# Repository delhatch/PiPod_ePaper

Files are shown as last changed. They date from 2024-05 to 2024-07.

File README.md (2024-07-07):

# PiPod_ePaper
This project takes the github.com/delhatch/PiPod project (which was derived from github.com/BramRausch/PiPod) and replaces the LCD screen with an e-Paper screen.
<table border="1">
  <tr>
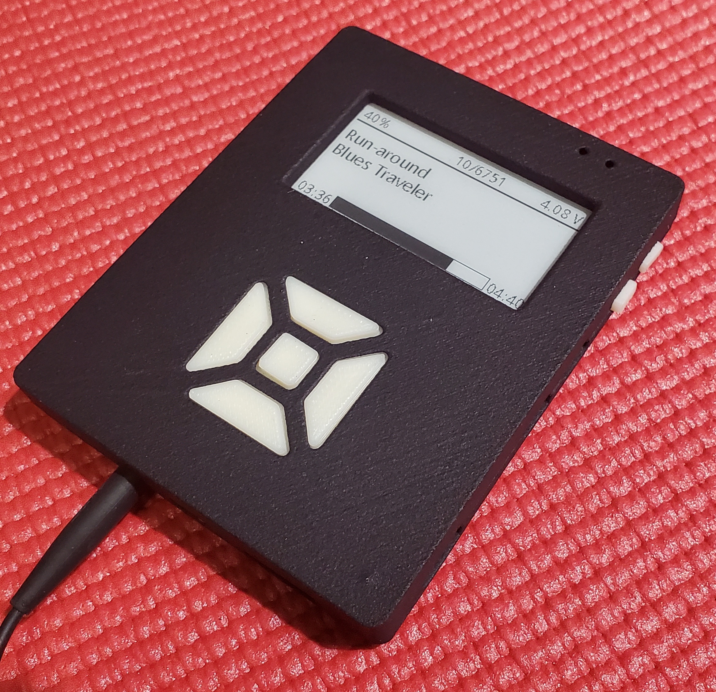
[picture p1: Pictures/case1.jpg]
   <td></td>
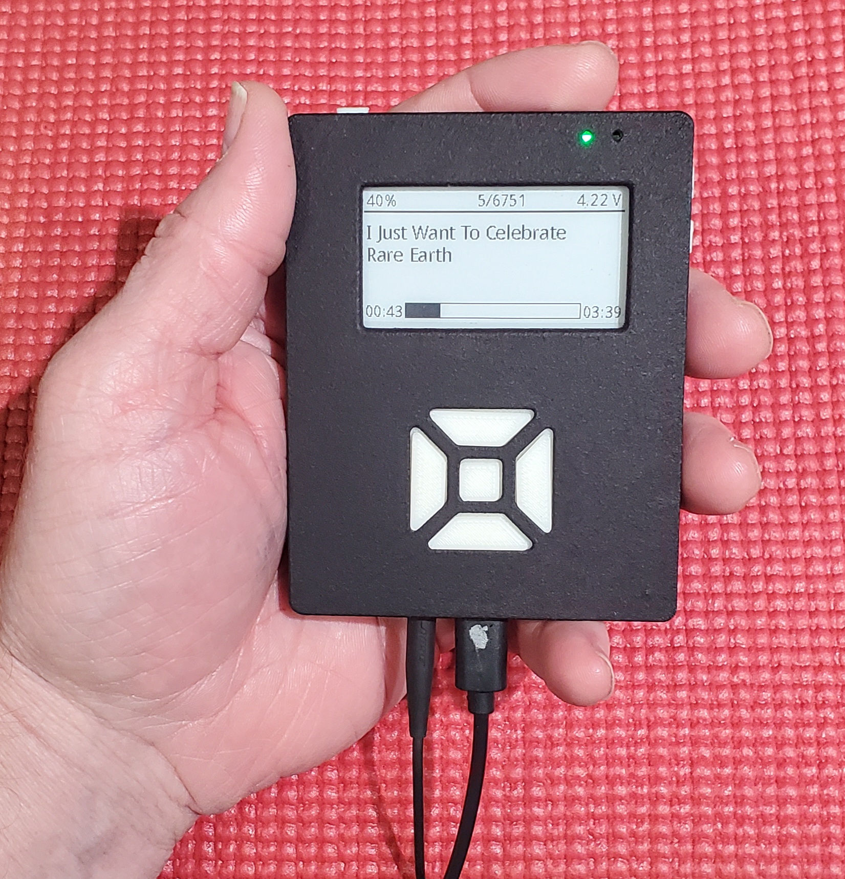
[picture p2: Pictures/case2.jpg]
   <td></td>
  </tr>
  <tr>
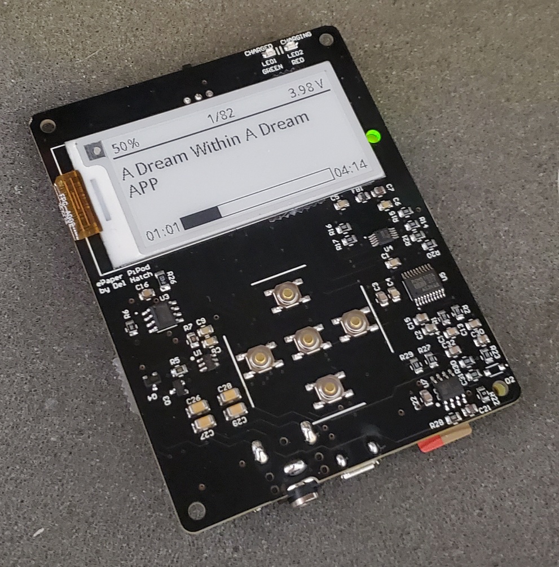
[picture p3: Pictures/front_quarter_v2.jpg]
   <td></td>
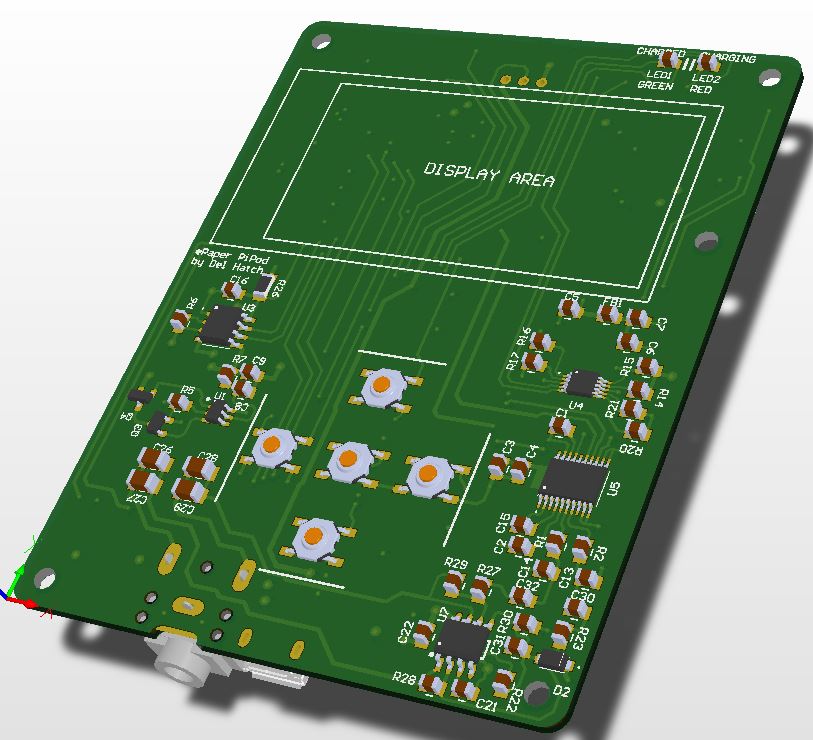
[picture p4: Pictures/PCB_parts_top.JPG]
   <td></td>
  </tr>
  <tr>
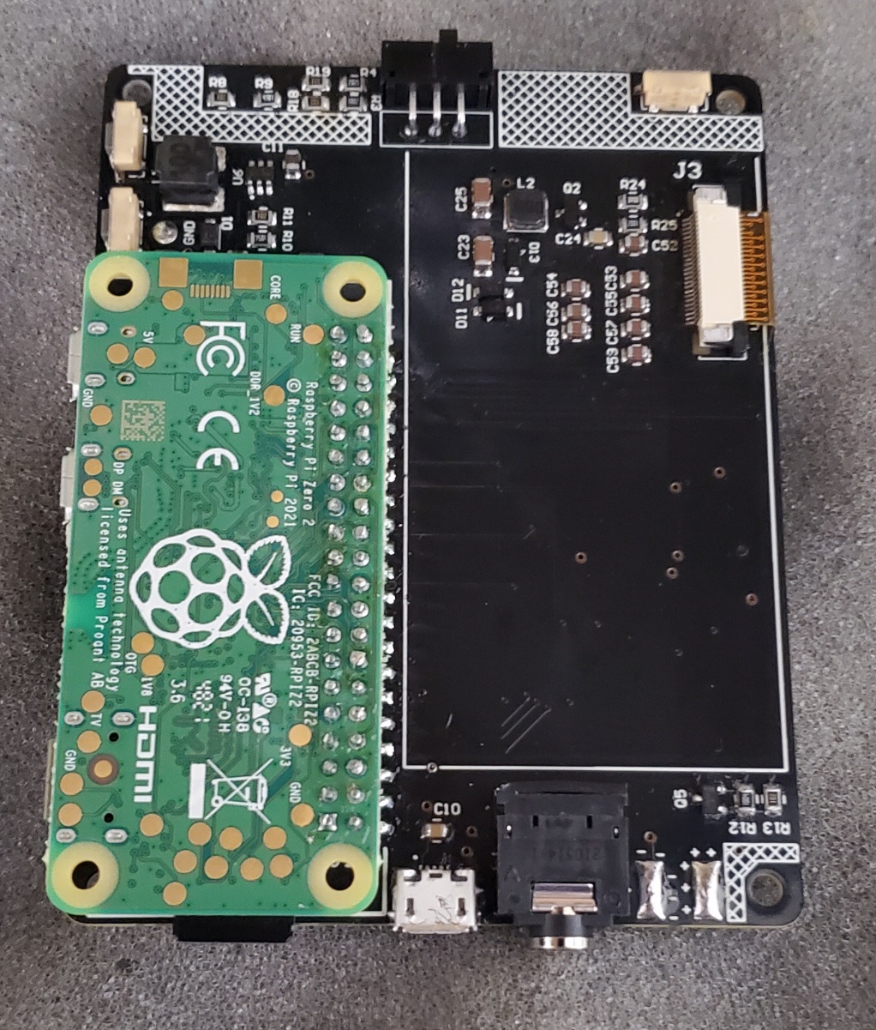
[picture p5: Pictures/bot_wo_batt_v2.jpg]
   <td></td>
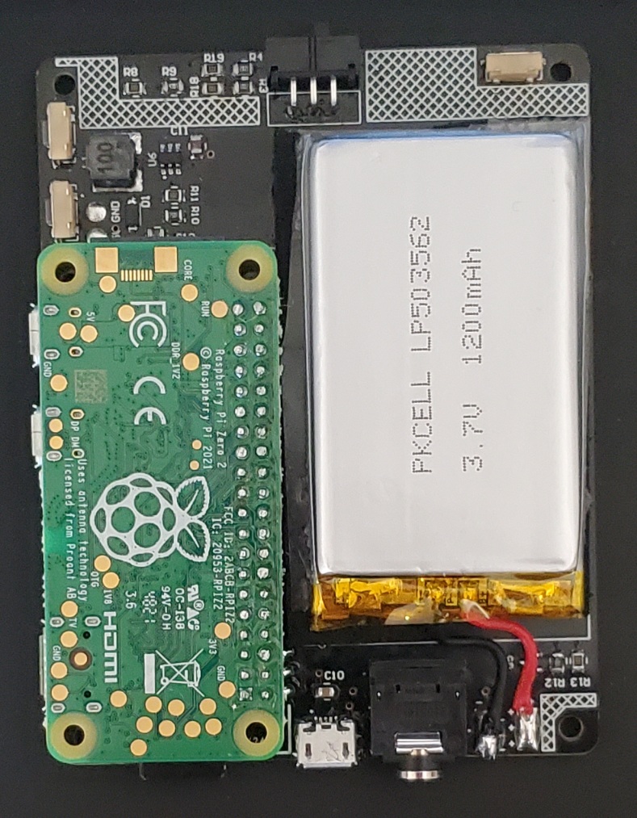
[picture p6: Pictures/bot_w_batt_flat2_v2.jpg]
   <td></td>
  </tr>
  <tr>
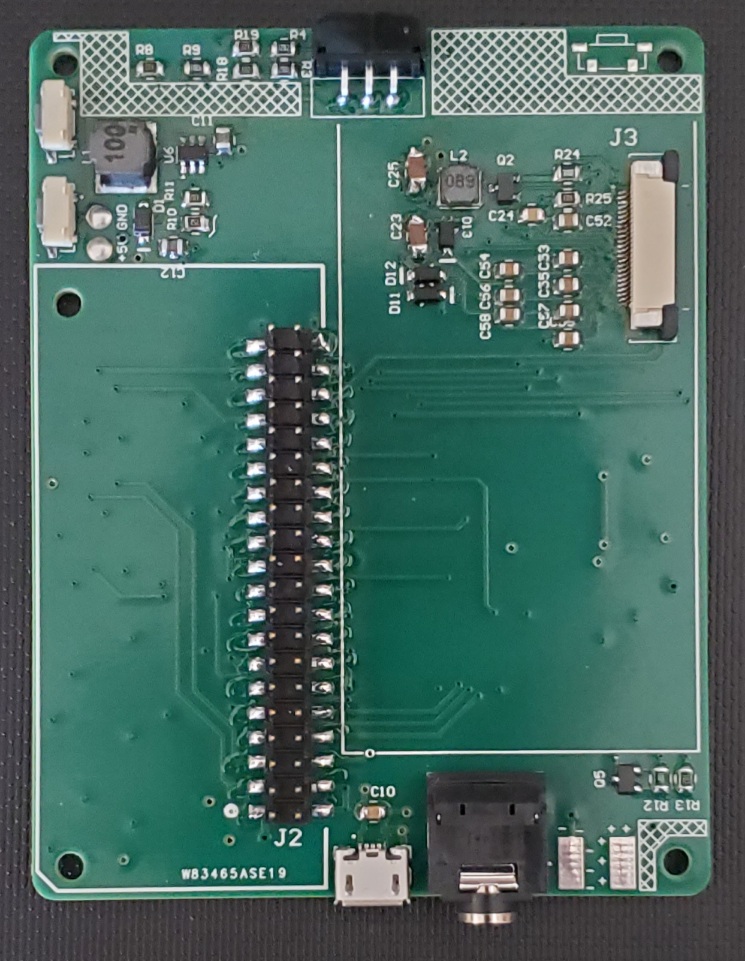
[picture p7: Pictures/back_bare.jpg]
   <td></td>
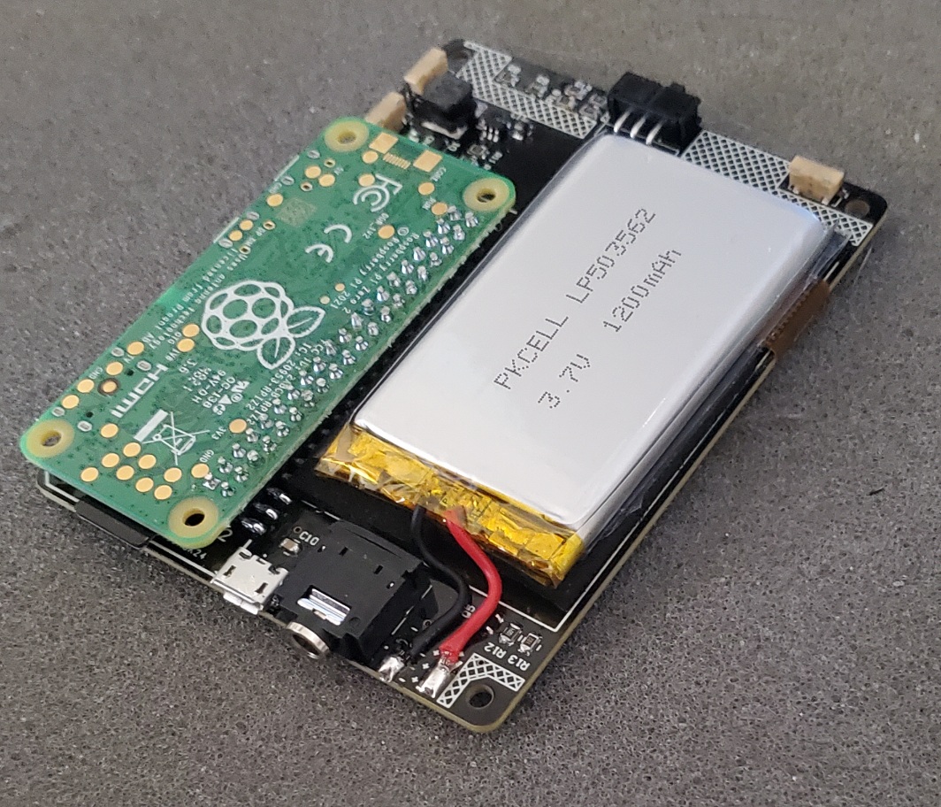
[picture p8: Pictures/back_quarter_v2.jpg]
   <td></td>
  </tr>
</table>
<h3>Motivation</h3>
<p>The goal of this project was switching from a 2.2" 320x240 LCD screen to a 2.13" 250x122 e-Paper screen (from Waveshare) in order to extend the battery run-time.</p>
<p>Using the project's standard 1200 mAh battery, the continuous play time is now <b>4 hours, 48 minutes</b>. Since a USB power supply is rarely far away, this seems sufficient.</p>
<p>In addition to using an e-paper screen, I also added a headphone amplifier based on the TP6113 IC. Note: This amplifier is rated at 40 mW, which does not sound like a lot of power, but even with inefficient headphones this equates to 108 dBSPL (equivalent to a gas lawn mower at 1m), which is far too loud for sustained listening. Watch your volume setting!</p>
<h3>Project Derivation</h3>
<p>This project is derived from github.com/delhatch/PiPod_Zero2W. This repository has changes to impliment the use of the e-Paper screen, along with other minor bug fixes.</p>
<h3>Structural Changes</h3>
<p>I have changed the OS to the "lite" version: 2024-03-15-raspios-bookworm-arm64-lite.img.xz This change reduces power consumption by ~20 mA, which is a 9% savings, so reasonably significant.</p>
<p>Also moved from Pygame to Pillow for the screen graphics.</p>
<p>Then I got rid of Pygame completely, since I was only using it for the key stroke buffer, and the Python keypad library was already taking care of that. Eliminating Pygame reduced power consumption by 9.2% when idle, and by 5.2% when playing music.</p>
<h3>Status</h3>
<p>28 June 2024: I built a unit with the Rev2 PCB (black PCB, see pics). It works great. The Rev3 (current) case files appear to be acceptable.</p>
<h3>Power Savings</h3>
<p>With the LCD screen, with the backlight on, during playback, the current draw is <b>266 mA</b>.</p>
<p>With the LCD screen, with the backlight off, during playback, the current draw is <b>220 mA</b>.</p>
<p>With the e-Paper screen, during playback, the current draw is <b>175 mA</b>.</p>
<p>Having eliminated Pygame, the current draw is down to only <b>166 mA</b>.</p>
<p>So the e-Paper screen is definitely a major improvement in battery life (playback time), and also useability because there is no anxiety about leaving an LCD backlight on.</p>
<h3>Known Bugs</h3>
<ul>
<li>None.</li>
</ul>
<h3>Features TODO</h3>
<ul>
  <li>Test "current draw vs. various refresh rates" for the top (Playing) screen. It updates every 5 seconds, which isn't bad actually, but if this can be reduced without costing too much power, it might be worth it. TBD.</li> 
  <li>Eliminate flashing screen on sub-menus.</li>
  <li>Impliment an "Adjust Audio EQ" screen.</li>
  <li>Restore playback state on power-up (restore the play list, and the currently-playing song).</li>
  <li>Add the use of a GPIO to mute the headphone amp on power-up?</li>
  <li>Determine if there is a need to install all of the waveshare github. Just need the 2 files in this repo?</li>
</ul>
<h3>Instructions</h3>
<p>Completion of these instructions takes about 40 minutes, not including the time transferring the music files.</p>
<p>The bare PC board and case parts can be ordered via this link at <a href="https://www.pcbway.com/project/shareproject/ePaper_PiPod_MP3_music_player_a6adf3e1.html">PCBWay</a>. For the case parts (top, bottom and frame parts) I specified 3D printing in Nylon: PA-12 with 35% glass fill. For the navigation and side buttons, 3D printing in any cheap white plastic will do.</p>
<a href="https://www.pcbway.com/project/shareproject/ePaper_PiPod_MP3_music_player_a6adf3e1.html">PCB from PCBWay</a>
<p>Instructions:</p>
<ul>
  <li>Download the OS file "2024-03-15-raspios-bookworm-arm64-lite.img.xz" or newer.</li>
  <li>Using rufus-3.22.exe (or similar), burn the image to a 128GB micro-SD card.</li>
  <li>Assuming you have a fully-assembled PiPod hardware: Connect an HDMI monitor to the Pi Zero 2 W. Also connect a USB expander hub such as the SmartQ H302S to the Pi Zero usb connector. Connect a USB keyboard to the hub.</li>
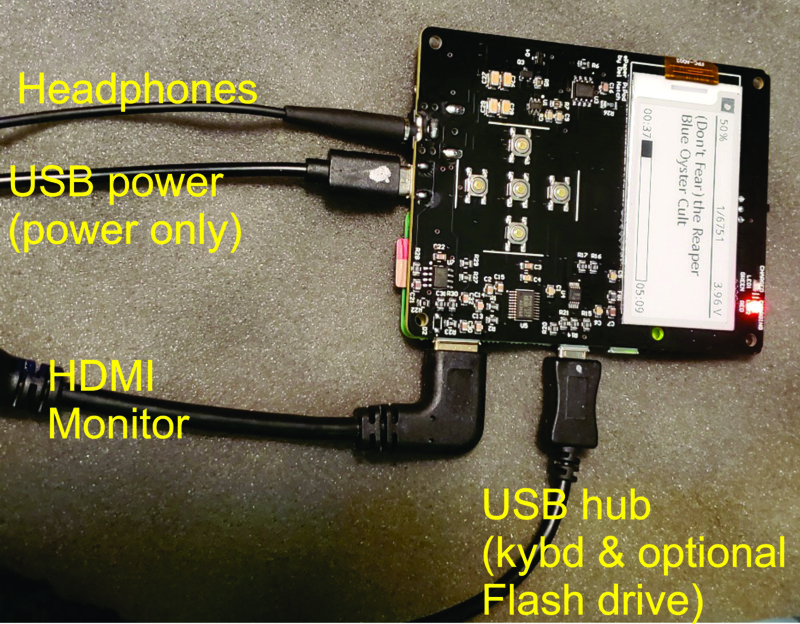
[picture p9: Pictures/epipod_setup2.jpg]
  
  <li>Insert the SD card into the Pi Zero 2 W slot.</li>
  <li>Apply power (from a plug-in USB power supply) to the USB connector at the bottom of the PiPod.</li>
  <li>Power-up and go through the configuration screens. Create the user "pi" with a password of your choosing. Reboot and log in.</li>
  <li>At the prompt: <code>sudo raspi-config</code>
    <ul>
      <li>Go into Menu Item #1, then select S1. Enter the SSID and passphrase for your wi-fi.</li>
      <li>Select menu item #1, then select S5 (Boot/Auto-login) select and enable "Console Autologin".</li>
      <li>From the top menu, select #3 "Interface Options" then select and enable I1 "Enable SSH".</li>
      <li>From the top menu, select #3 "Interface Options" then select and enable I4 "Enable I2C".</li>
      <li>Select "Back" to top screen, then "Finish" and then reboot.</li>
    </ul></li>
  <li>Type: <code>sudo nano /boot/firmware/config.txt</code> and make the following changes:
    <ul>
      <li>If necessary, un-comment <tt>dtparam=spi=on</tt> (to turn on the SPI port)</li>
      <li>comment-out the <tt>dtparam=audio=on</tt> line</li>
      <li>If necessary, un-comment the line <tt>dtparam=12c_arm=on</tt></li>
      <li>At the end of the file, add a line: <tt>dtoverlay=hifiberry-dac</tt></li>
      <li><tt>CTRL-O</tt> and <tt>ENTER</tt> and <tt>CTRL-X</tt> to save and exit.</li>
  </ul>
</li>
  <li><code>sudo reboot</code></li>
  <li>Enter the following lines to install the required packages:
  <ul>
    <li><code>sudo apt install python3</code></li>
    <li><code>sudo apt install build-essential python3-dev python3-smbus -y</code></li>
    <li><code>sudo apt install git -y</code></li>
    <li><code>sudo apt install python3-vlc -y</code></li>
    <li><code>sudo apt install python3-alsaaudio -y</code></li>
    <li><code>sudo apt install pulseaudio -y</code></li>
    <li><code>sudo apt install python3-taglib -y</code></li>
    <li><code>sudo apt install python3-spidev -y</code></li>
    <li><code>sudo apt install python3-gpiozero -y</code></li>
    <li><code>sudo apt install python3-pip -y</code></li>
    <li><code>sudo apt install python3-pil -y</code></li>
    <li><code>sudo apt install python3-numpy -y</code></li>
  </ul>
</li>
<li><code>sudo reboot</code></li>
<li>Verify that the audio is working. Plug headphones into the PiPod and type:
  <ul>
    <li><code>sudo raspi-config</code></li>
    <li>Select line #1, then #2 "Audio"
    <li>Select snd_rpi_hifiberry_dac then Finish</li>
    <li>type: <code>amixer set Master 50%</code></li>
    <li>type: <code>speaker-test -c2</code></li>
    <li>Verify that audio is coming from the headphones and not the HDMI monitor.</li>
    <li><tt>CTRL-C</tt> to finish and quit.</li>
  </ul>
</li>
<li>Install the Adafruit_GPIO library:
  <ul>
    <li>from the home directory (<code>~/</code>) type: <code>git clone https://github&#46;com/adafruit/Adafruit_Python_GPIO.git</code></li>
    <li><code>cd Adafruit_Python_GPIO</code></li>
    <li><code>sudo python3 setup.py install</code></li>
  </ul>
<li>Install the Adafruit Blinka library:
  <ul>
    <li><code>cd ~/</code></li>
    <li><code>sudo pip3 install --break-system-packages Adafruit-Blinka</code></li>
  </ul>
</li>
<li>Install the waveshare e-Paper libraries:
  <ul>
    <li><code>cd ~/</code></li>
    <li><code>git clone https://github&#46;com/waveshare/e-Paper.git</code></li>
    <li><code>sudo pip3 install --break-system-packages waveshare-epaper epd-library</code></li>
  </ul></li>
<li><code>sudo reboot</code></li>
<li>Now fetch the e-Paper MP3 player software from this repository:
  <ul>
    <li><code>cd ~/</code> then type: <code>git clone https://github&#46;com/delhatch/PiPod_ePaper.git</code></li>
    <li><code>cd PiPod_ePaper</code></li>
    <li><code>mv launch.sh ~/.</code></li>
    <li><code>cd ~/</code></li>
    <li><code>chmod 777 launch.sh</code></li>
    <li><code>mkdir .config/systemd</code></li>
    <li><code>mkdir .config/systemd/user</code></li>
    <li><code>cd PiPod_ePaper</code></li>
    <li><code>mv pipod.service ~/.config/systemd/user/.</code></li>
    <li><code>mv -f epd2in13_V4.py ~/e-Paper/RaspberryPi_JetsonNano/python/lib/waveshare_epd/.</code></li>
    <li><code>mv -f epdconfig.py ~/e-Paper/RaspberryPi_JetsonNano/python/lib/waveshare_epd/.</code></li>
  </ul>
</li>
<li>Create the directory: <code>mkdir ~/Music</code></li>
<li>Move your music files into this Music directory. You can do this two ways:
  <ul>
    <li>Method 1: Insert a USB Flash stick into the USB hub, and cp the files over.
      <ul>
        <li><code>sudo mount /dev/sda1 /mnt/usb</code> (You'll need to sudo mkdir the /mnt/usb directory)</li>
        <li>After copying, <code>sudo umount /mnt/usb</code> then remove the USB stick.</li>
      </ul>
    </li>
    <li>Method 2: Type: <code>ifconfig</code> and note the IP address. Use the application WinSCP, and use the SFTP protocol, to copy media files from a Windows computer to the PiPod.</li>
  </ul>
</li>
<li>You should now be able to launch the PiPod software, with everything working.
  <ul>
    <li>cd into the directory: <code>cd ~/PiPod_ePaper/Software</code></li>
    <li>Type: <code>python3 main.py</code></li>
    <li>Note that when launching for the first time, it will scan the music files and create an index file. This may take a minute or two.</li>
  </ul>
</li>
<li>To have the PiPod automatically run the player automatically on power-on:
  <ul>
    <li>To activate the pipod.service file, at the prompt, type: <code>systemctl --user enable pipod.service</code></li>
    <li>Reboot. If there are problems, type: <code>systemctl --user status pipod.service</code> to see if the service launched.</li>
  </ul>
</li>
  <li>To minimize battery power consumption: disable wifi, bluetooth, and reduce the CPU clock speed.
  <ul>
    <li><code>sudo nano /boot/firmware/config.txt</code></li>
    <li>After the line "dtparam=spi=on add these new lines:
    <ul>
      <li><code>dtoverlay=disable-wifi</code></li>
      <li><code>dtoverlay=disable-bt</code></li>
    </ul></li>
    <li>Under the line "Enable DRM VC4 V3D driver", comment out the 2 lines that follow.</li>
    <li>Comment out the line <code>display_auto_detect=1</code></li>
    <li>Under the line "Run as fast as firmware board allows"
      <ul>
        <li>comment out <code>arm_boost=1</code></li>
        <li>add the lines:
          <ul>
            <li><code>arm_freq=150</code></li>
            <li><code>core_freq=150</code></li>
            <li><code>over_voltage=-4</code></li>
          </ul></li></li>
      </ul>
  </li>
</ul>
<h3>Operating Procedure</h3>
<p>To charge the battery, slide the top power switch to the left. Connect a USB power supply to the USB jack at the bottom of the PiPod. Applying power will start charging the battery, and will also boot the PiPod.</p>
<p>To shutdown the PiPod, press the up arrow to get into the menu tree. Press the down arrow to "Shutdown". Press the middle button.</p>
<p>To operate from battery power, you MUST start with the ePiPod in the shutdown state. Do not run from USB power (power switch to the left) and then slide the power switch to the right (battery power). This causes a power glitch. Simply start with an ePiPod in the shutdown state, and slide the power switch to the right. Wait for it to boot.</p>
<p>While operating from battery power, you can plug (and unplug) the bottom USB jack into a power source to charge the battery.</p>
<p>To shutdown from battery power, find and press the "Shutdown" command as above. After 5 seconds (and with the bottom USB jack <b>NOT</b> connected to a power source), slide the top power switch to the left.</p>

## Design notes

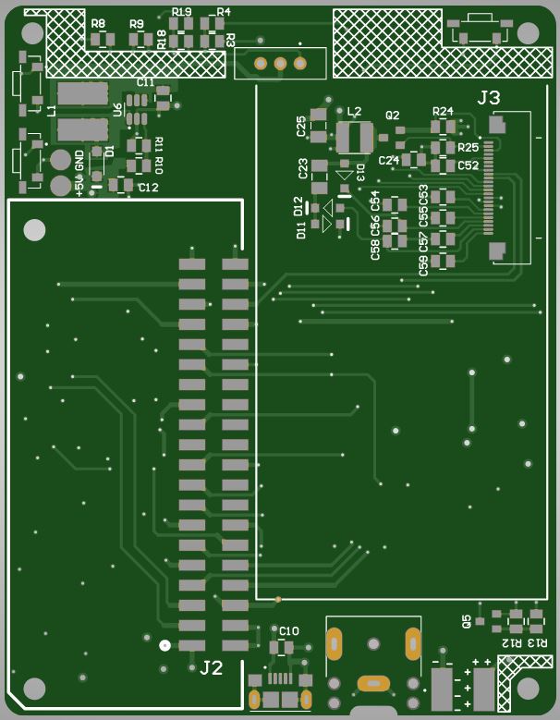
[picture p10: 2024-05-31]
Pictures/PCB_bottom.JPG

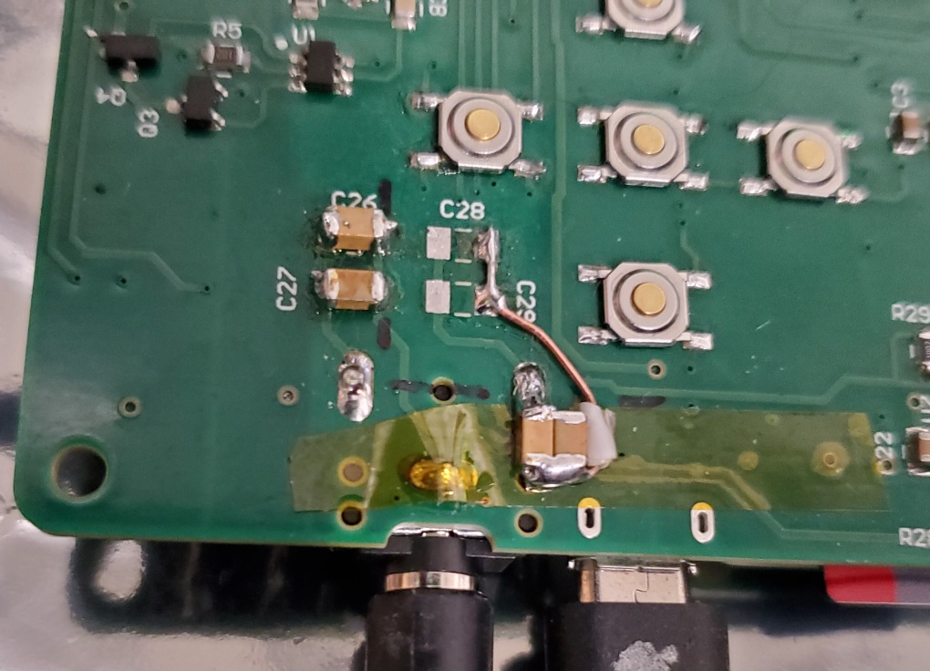
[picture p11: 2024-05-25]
Pictures/patch.jpg

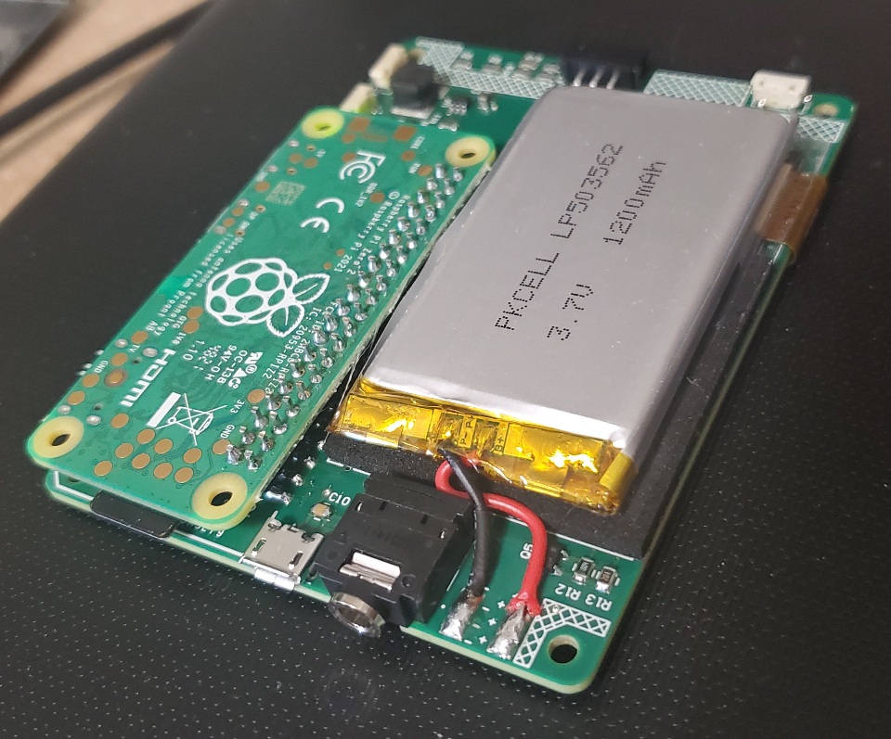
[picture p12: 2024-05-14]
Pictures/back3.jpg

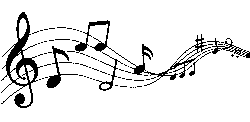
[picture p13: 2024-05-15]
music1.bmp

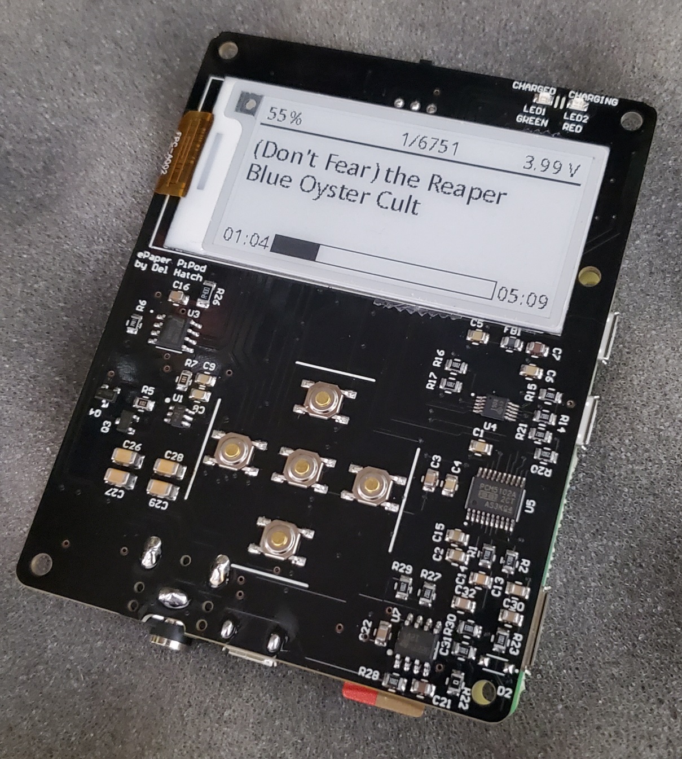
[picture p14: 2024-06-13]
Pictures/top_v2.jpg

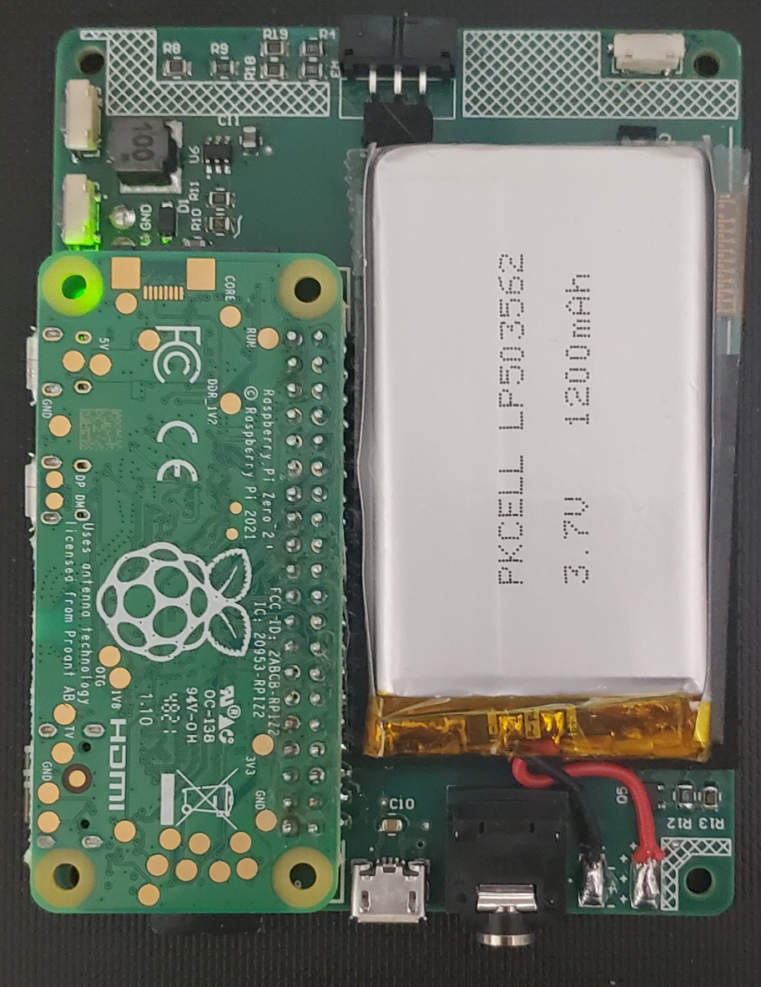
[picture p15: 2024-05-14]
Pictures/back1.jpg

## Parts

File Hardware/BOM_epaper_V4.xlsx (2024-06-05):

Ref Designator | Description | Value | Package | Digikey Part No. | Quantity | Price | Ext.Price | On-hand | Ordered
R7 |  | 100R | 0805 | 311-100CRCT-ND | 1 | $0.10 | $0.10
R1, R2 | Thin Film (low noise) | 470R | 0805 | 13-RT0805FRE07470RLCT-ND | 2 | $0.10 | $0.20
R3, R14-R17, R20, R21, R23, R25, R27-R29 | Thin Film (low noise) | 10K | 0805 | YAG1239CT-ND | 12 | $0.04 | $0.42
R4 |  | 12K | 0805 | 13-RT0805FRE0712KLCT-ND | 1 | $0.10 | $0.10
R5, R8, R11, R13, R18 |  | 1k | 0805 | RHM1.0KBCT-ND | 5 | $0.10 | $0.50
R6 |  | 3k9 | 0805 | 13-RT0805FRE073K9LCT-ND | 1 | $0.10 | $0.10
R9 |  | 4K7 | 0805 | 13-RT0805FRE074K7LCT-ND | 1 | $0.10 | $0.10
R12 |  | 1M | 0805 | 13-RT0805FRE071MLCT-ND | 1 | $0.10 | $0.10
R19 |  | 1k2 | 0805 | RHM1.2KKCT-ND | 1 | $0.10 | $0.10
R10 |  | 7k5 | 0805 | 13-RT0805FRE077K5LCT-ND | 1 | $0.10 | $0.10
R22 | Only if using U7 (alt) | 0 ohm | 0805 | 311-0.0ARCT-ND | 1 | $0.10 | $0.10
R24 |  | 3R | 0805 | RC0805FR-073RL | 1 | $0.10 | $0.10
R26 |  | 0.4 ohm | 1206 | 13-RL1206JR-070R4LCT-ND | 1 | $0.27 | $0.27
R30 |  | 100k | 0805 | YAG3359CT-ND | 1 | $0.10 | $0.10
C13, C14 | 25V | 2.2nF | 0805 | 732-8051-1-ND | 2 | $0.10 | $0.20
C1, C4, C5, C6, C8-C10, C24 | 25V | 0.1uF | 0805 | 1276-1286-1-ND | 8 | $0.04 | $0.34
C2, C15 | 10V | 2.2uF | 0805 | 1276-1188-1-ND | 2 | $0.11 | $0.22
C3, C16, C22 | 10V | 10uF | 0805 | 1276-6456-1-ND | 3 | $0.11 | $0.33
C11, C12 | 16V, low ESL | 22uF | 0805 | 445-14486-1-ND | 2 | $0.36 | $0.72
C23, C25 | 50V, low ESL | 4.7uF | 1206 | 445-8032-1-ND | 2 | $0.68 | $1.36
C30, C32 | 25V | 4.7uF | 0805 | 1276-1244-1-ND | 2 | $0.10 | $0.20
C7, C21, C31, C52-59 | 50V, low ESL | 1 uF | 0805 | 445-7547-1-ND | 11 | $0.18 | $2.01
C26-C29 | 6.3V | 220 uF | 1206 | 490-13970-1-ND | 4 | $1.17 | $4.68
D1, D2 | 40V, 3A | SS34 | SOD-123W | 1801-SS34LWHCT-ND | 2 | $0.42 | $0.84
D11,D12,D13 | 30V, 0.5A | MBR0530 | SOD-123 | 1765-MBR0530CT-ND | 3 | $0.34 | $1.02
FB1 | Ferrite bead | MPZ2012S102A | 0805 | 445-MPZ2012S102AT000CT-ND | 1 | $0.12 | $0.12
J1 | Audio jack | 35RAPC2BHN2 | 3.5mm | SC1458-ND | 1 | $1.97 | $1.97
J2 | Raspi connector | 2x20 0.1" SMT 40-pin header | 0.1" | 609-2231-ND | 1 | $3.09 | $3.09
J3 | e-Paper connector | FFC FPC top 24POS 0.5mm R/A | 0.5mm | 609-F32Q-1A7H1-11024CT-ND | 1 | $0.78 | $0.78
J4 | USB connector | FCI-10103594-0001LF | 0.65mm SMD | 609-4616-1-ND | 1 | $0.46 | $0.46
L1 | 2.8A | 10 uH | 2424 | 732-78404064100CT-ND | 1 | $1.41 | $1.41
L2 | 1.1A, 1.8mm height | 68 uH | non-std | 732-7237-1-ND | 1 | $1.20 | $1.20
LED1 | Green LED | IN-S85ATG | 0805 | 1830-1079-1-ND | 1 | $0.34 | $0.34
LED2 | Red LED | IN-S85ATR | 0805 | 1830-1082-1-ND | 1 | $0.34 | $0.34
S1-S3 | Side push-button | TL3330 | SMD | EG4388CT-ND | 3 | $0.51 | $1.53
S4-S8 | Push-button switch | TL3342 | SMD | EG2531CT-ND | 5 | $0.63 | $3.13
S9 | Power Switch, SPDT | EG1218 | TH | EG1903-ND | 1 | $0.76 | $0.76
Q2, Q5 | N-Channel MOSFET | CPH3457-TL-H | SOT-23-3 | CPH3457-TL-H-ND | 2 | $0.50 | $1.00
Q2, Q5 (alt) | N-Channel MOSFET | IRLML6346TR | SOT-23-3 | IRLML6346TRPBFCT-ND | 2 | $0.46 | $0.92
Q3, Q4 | N-Channel MOSFET | AO3416 | SOT-23-3 | 785-1011-1-ND | 2 | $0.25 | $0.50
U1 | Battery protection | FS312F-G | SOT-23-6 | eBay | 1 | $0.13 | $0.13
U3 | Li-ion battery charger | TP4056 | SOP-8 | eBay | 1 | $1.19 | $1.19
U4 | 16-bit ADC | ADS1115IDGSR | VSSOP-10 | 296-38849-1-ND | 1 | $5.57 | $5.57
U5 | Stereo DAC | PCM5102APWR | TSSOP-20 | 296-36707-1-ND | 1 | $4.79 | $4.79
U6 | Boost converter | MT3608 | SOT-23-6 | eBay | 1 | $1.00 | $1.00
U7 | Headphone amp | TPA6113A2DR | SOIC-8 | 296-TPA6113A2DRCT-ND | 0 | $1.21 | $0.00
U7 (alt) | Headphone amp, alt | TS482 | SOIC-8 | 497-2287-1-ND | 1 | $1.10 | $1.10
MISCELLANEOUS
BATT1 | LiPo 1200mAh battery |  |  | Adafruit #258 | 1 | $9.95 | $9.95
Raspberry Pi Zero 2 W |  |  |  | www.pishop.us | 1 | $15.00 | $15.00
Bare PC board | PCBWay |  |  | https://www.pcbway.com/project/shareproject/ePaper_PiPod_MP3_music_player_a6adf3e1.html | 1 | $5.00 | $5.00
DISP1 | 2.13 inch e-Paper display |  |  | Waveshare #12672 | 1 | $6.99 | $6.99
Case, Top | Same link as ordering the PCB, from PCBWay. |  |  | https://www.pcbway.com/project/shareproject/ePaper_PiPod_MP3_music_player_a6adf3e1.html | 1 | $12.45 | $12.45
Case, Bottom |  |  |  |  | 1 | $12.45 | $12.45
Case, internal support |  |  |  |  | 1 | $12.45 | $12.45
Foam tape battery padding | 0.094" (2.38mm) 3/32" | ZUSAESR-33 |  | 4753-ZUSAESR-33-ND | 1 | $0.92 | $0.92
 |  |  |  |  |  |  | $120.86

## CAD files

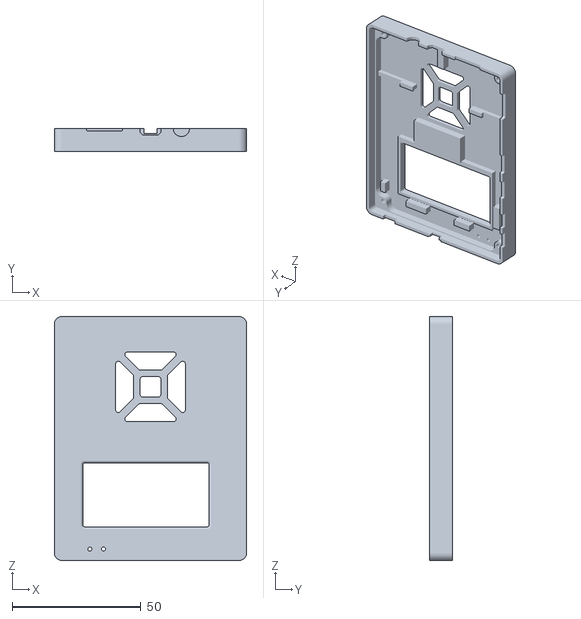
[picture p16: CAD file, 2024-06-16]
Case/PiPod_TopCase v39.stl
74.6 x 9.02 x 94.6

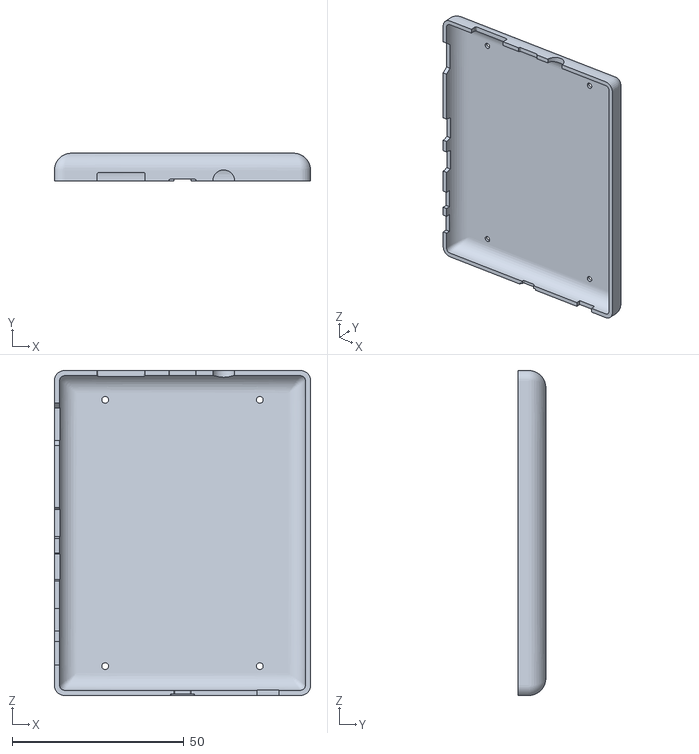
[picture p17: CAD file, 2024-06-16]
Case/PiPod_case_bottom v18.stl
74.6 x 8.05 x 94.6

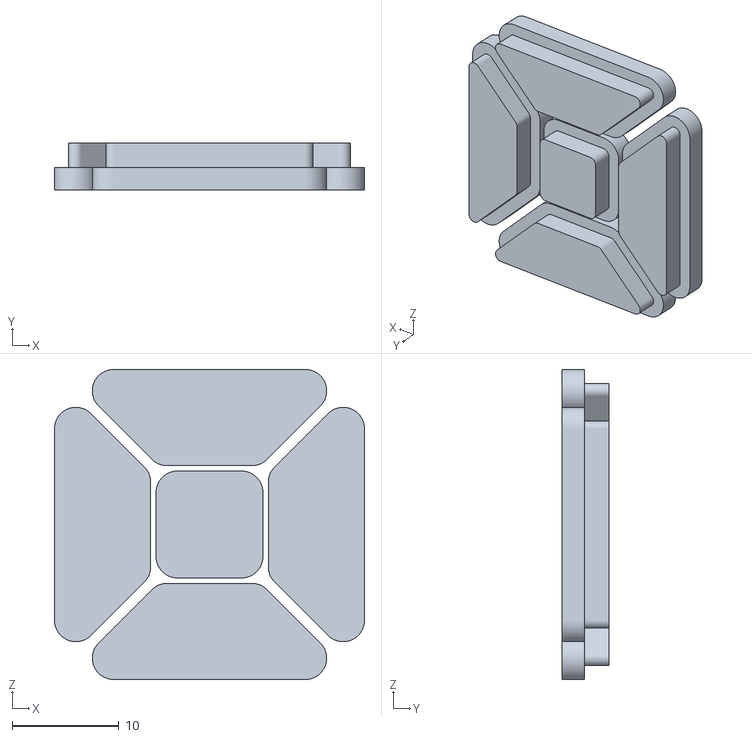
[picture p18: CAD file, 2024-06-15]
Case/PiPod_Navigation_buttons_v3 v3.stl
29.0 x 4.38 x 29.0

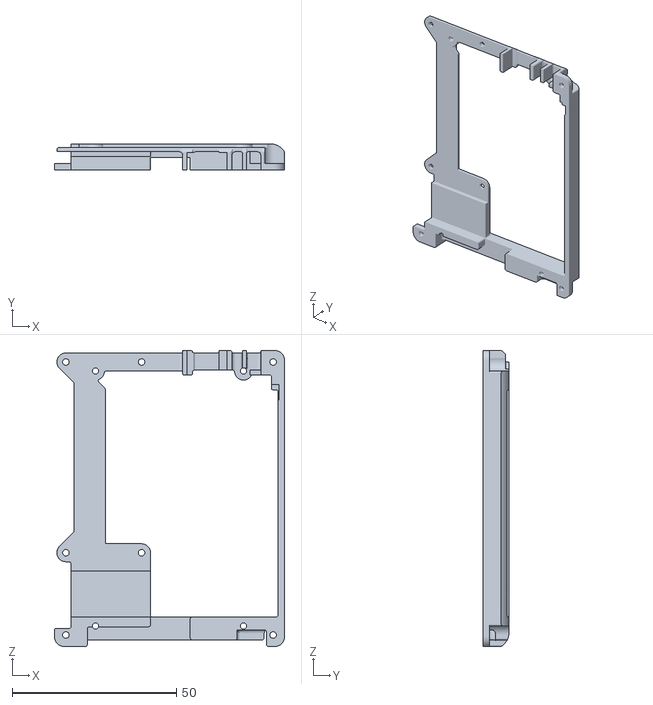
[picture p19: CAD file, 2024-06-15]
Case/PiPod_Frame_v4 v10.stl
70.0 x 8.00 x 90.0

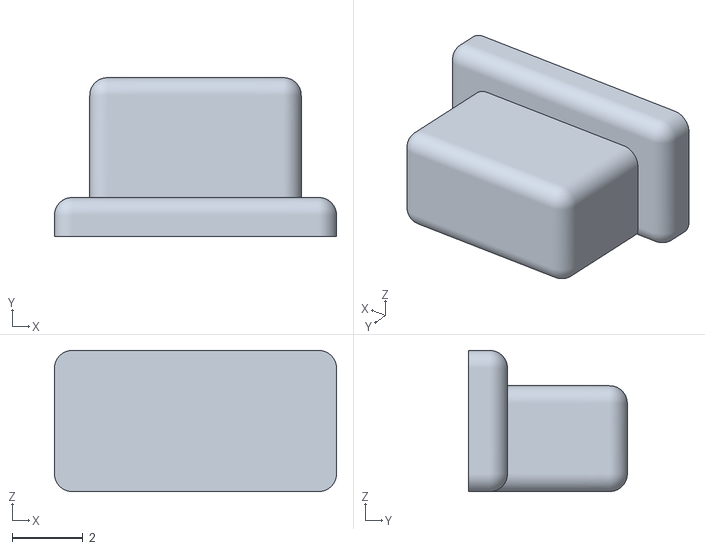
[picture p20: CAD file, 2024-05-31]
Case/Button (side).stl
8.00 x 4.50 x 4.00

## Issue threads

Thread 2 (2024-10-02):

Updfating Library

hokuto123456789, 2024-10-02:
hello. Please let me know because I can't get it right while I'm creating it.

1. Put MP3 files in Music folder
2. Menu Settings Select Update Library

I get an error like the one below and can't return to the menu.
Is there a solution?

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

pi@raspberrypi:~/PiPod_ePaper/Software $ python3 main.py
Traceback (most recent call last):
  File "/home/pi/PiPod_ePaper/Software/main.py", line 142, in <module>
    music.updateLibrary()  # Re-create the info.csv file
    ^^^^^^^^^^^^^^^^^^^^^
  File "/home/pi/PiPod_ePaper/Software/playback.py", line 283, in updateLibrary
    stringTitle = newtitle[0].lstrip()
                  ^^^^^^^^
UnboundLocalError: cannot access local variable 'newtitle' where it is not associated with a value

delhatch, 2024-10-03:
I can think of a few things to do:
* look at the info.csv file. It should contain a CSV list of titles, artists, etc...
* look at the playback.py code near the end (lines 330-334). There are some debug print lines you can un-comment to see what the code sees as it parses the files in the Music directory.
* Make sure either your music files have filenames like "James Taylor - Steamroller.mp3" AND that the UseMeta is set to False  (line 15), OR
* Set UseMeta to True. Once set to True, info.csv will be built/made/created using the metadata contained in the music file itself, ignoring the file names.

My guess is that the lines 330-334 will print out which music file(s) are causing a problem during the creation of info.csv.

If all else fails, you can modify the parser to extract the music file metadata from whatever system/method your filenames use.

hokuto123456789, 2024-10-05:
Thank you. If you set the file name of the music file to something like "James Taylor - Steamroller.mp3", it will be recognized. I couldn't find this rule.
・ I was able to play music, but it is full of noise, so I will try to find the cause.
When D1 is removed, there is noise, but D1 parts are arranged and reattached.

hokuto123456789, 2024-10-08:
Using D2 instead of D1 is a mistake, but it always makes noise whether you run it on USB power or battery power. Is there a solution?
I created two boards, and both have the same symptoms.

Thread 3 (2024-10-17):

Lots of noise.

hokuto123456789, 2024-10-17:
Hello. I just finished installing the parts, but there is a lot of noise, and the music is noisy, whether it is USB powered or battery powered. Is it a specification that there is a lot of noise?
I have built two units and both are the same.
Bluetooth and Wifi are off.
Where can I check this to get rid of the noise?

delhatch, 2024-10-17:
I have never seen this symptom, but I can think of a few things to try:
1) There are 2 ways to stuff the circuit board in the amplifier section. Double-check ensure that only ONE of the two methods has been done. See the main schematics (note in the lower right) or the attached snippet image.
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
2) Using probes or wires, hook up headphones or an amplifier to pin 6 and/or 7 of U5. This is the audio just prior to the headphone amplifier. If it sounds good there, but bad at the headphone jack, then you know there is a problem in the headphone amplifier section. Probably related to the 2 stuff options.
Good luck!

hokuto123456789, 2024-10-19:
Thank you very much.

I did not notice the annotation in the lower right corner. My apologies.
**As it turns out, the noise is gone.**

I made one TS482 type and one TPA6113 type.
I modified it as shown in the annotation on the bottom right.
However, at first the TS482 noise did not disappear, and the other TPA6113 still has noise but it disappeared a little.

The cause of the noise in TS482 turned out to be a broken 0-ohm resistor in R22. After replacing this, the noise disappeared.

TPA6113 also did not completely eliminate the noise, so at the last minute I changed to the TS482 specification, and the noise did not bother me as much.

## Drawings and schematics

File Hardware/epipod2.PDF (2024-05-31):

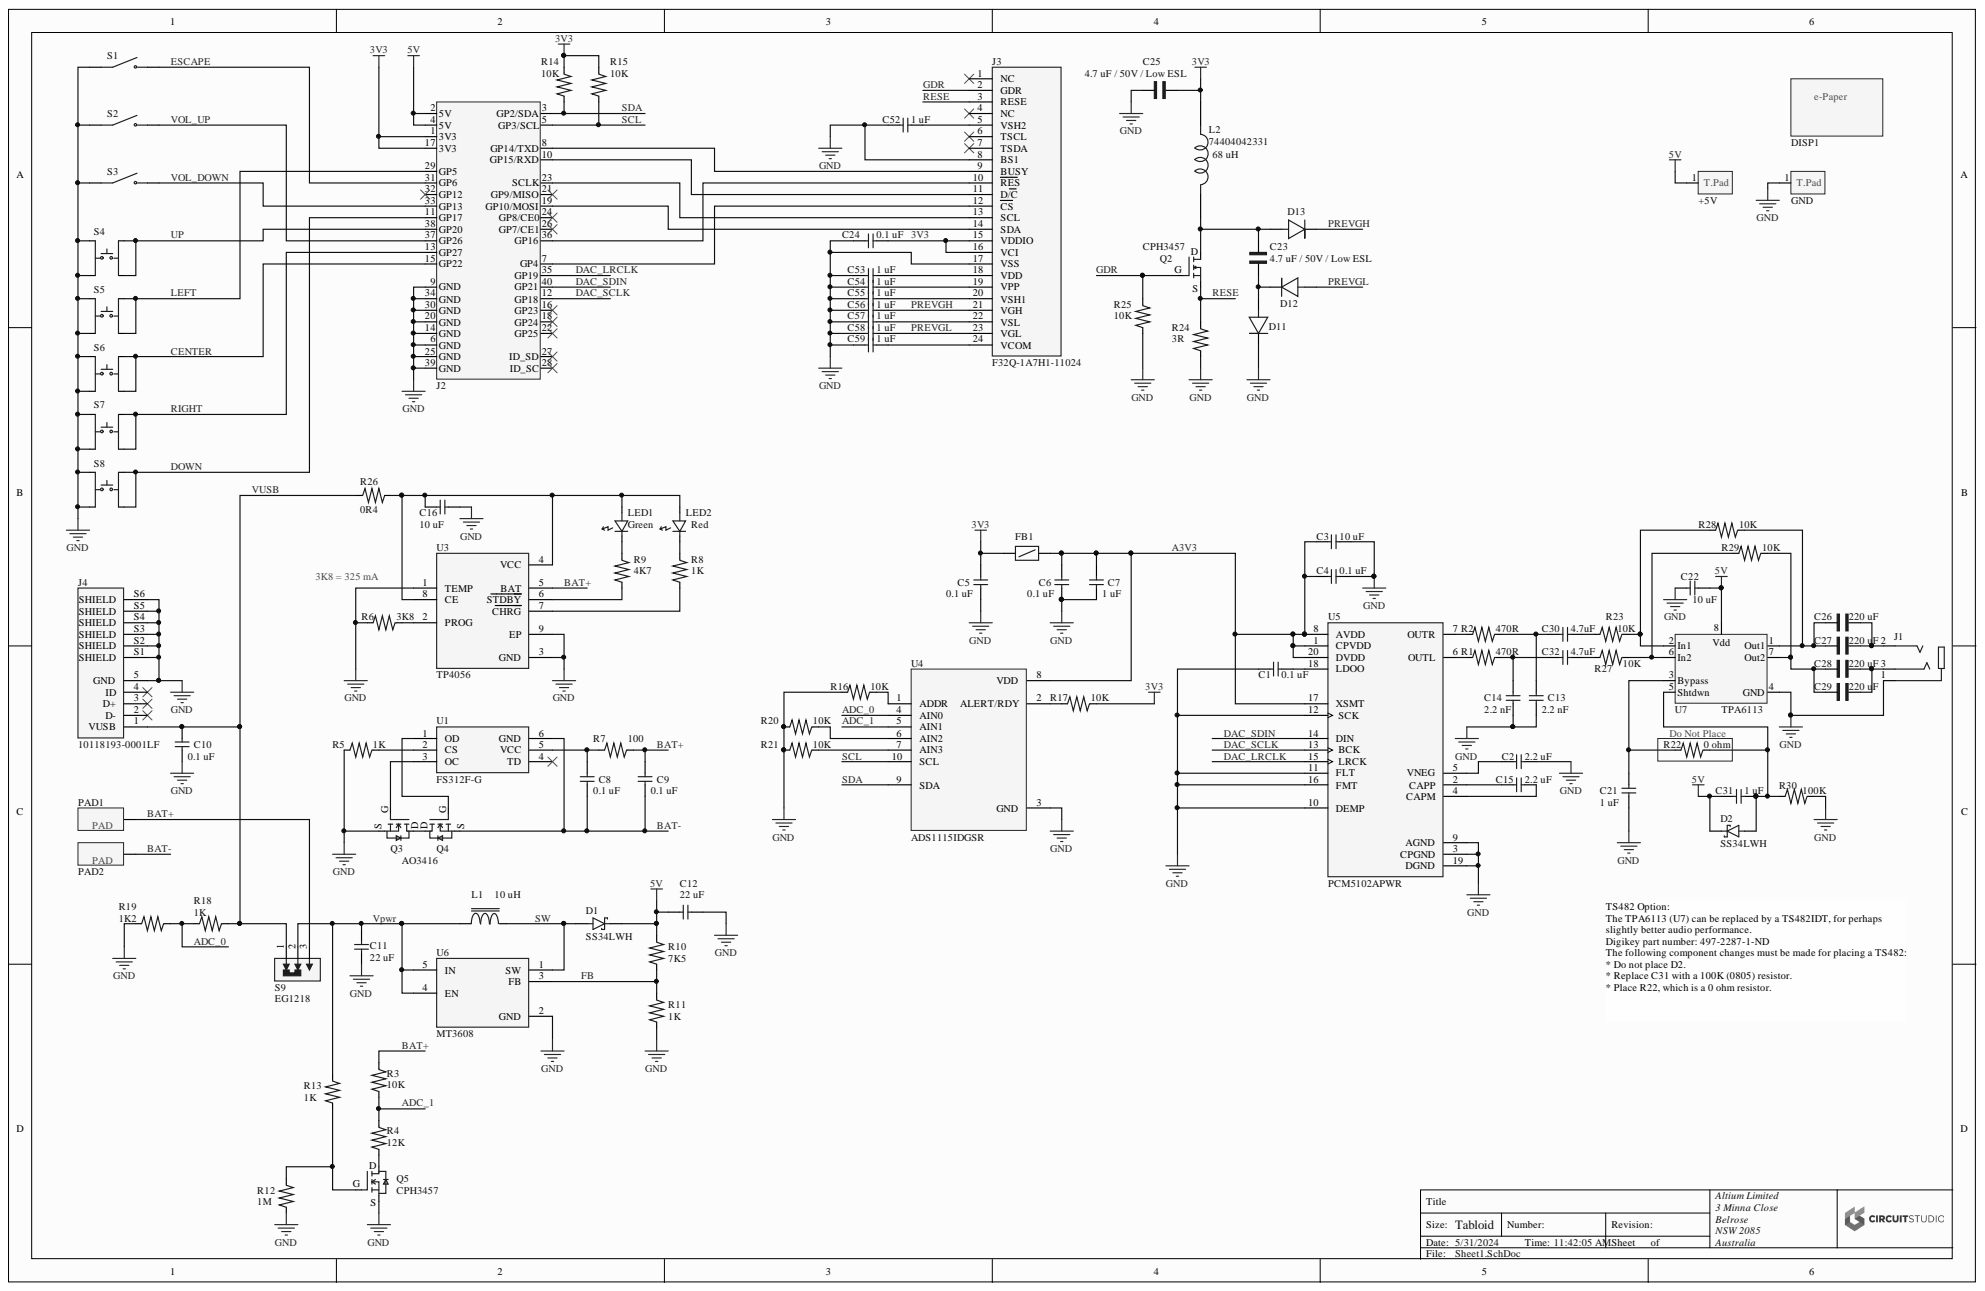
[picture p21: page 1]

GND | BUSY 9

GP13 33 | | CS 12
GP17 11 | SCL 13
GP20 38 | | SDA 14

FMT 16

DEMP 10

TS482 Option:
The TPA6113 (U7) can be replaced by a TS482IDT, for perhaps
slightly better audio performance.
Digikey part number: 497-2287-1-ND
The following component changes must be made for placing a TS482:
* Do not place D2.
* Replace C31 with a 100K (0805) resistor.
* Place R22, which is a 0 ohm resistor.

U6
IN 5

Title | Altium Limited 3 Minna Close Belrose NSW 2085 Australia

Size: Tabloid | Number: | Revision:

Date: 5/31/2024 Time: 11:42:05 AM | | Sheet of
File: Sheet1.SchDoc

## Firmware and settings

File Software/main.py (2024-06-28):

import playback
import display
import navigation
import device
import sys
import os
import time

# How often to update the top screen, in tenths of a second (50 = 5 seconds).
refreshTime = 50

# Provide a name for the values that PiPod.getKeyPressed() will return
K_u = 0
K_d = 1
K_UP = 2
K_DOWN = 3
K_LEFT = 4
K_RIGHT = 5
K_RETURN = 6
K_ESCAPE = 7

def needToUpdate():
    # Call every Class's method to see if they modified the screen
    need = False
    if( view.query4Update() ):
        need = True
        view.clearUpdateFlag()
    if( music.query4Update() ):
        need = True
        music.clearUpdateFlag()
    if( menu.query4Update() ):
        need = True
        menu.clearUpdateFlag()
    return need

music = playback.music()
music.enableEQ()
view = display.view()
menu = navigation.menu()
PiPod = device.PiPod()

updateScreenCounter = 0
refreshNow = False
stopRefreshing = False

# Check to see if a music metadata file has been created. If not, create one.
try:
    with open("/home/pi/info.csv", "r") as myFile:
        myFile.close()
except FileNotFoundError:
    view.popUp("Updating Library\nPlease Wait...")
    music.updateLibrary()  # This creates the info.csv file by reading every .MP3 file metadata.
menu.loadMetadata()   # This reads the info.csv file
status = PiPod.getStatus()
songMetadata = music.getStatus()

# Set the display of the playback mode to match the actual playback mode.
view.setPlayMode( music.getPlaybackMode() )
# Cause the screen to be drawn immediately.
menu.setUpdateFlag()

while True:
    music.loop()    # Checks if song has ended, and starts playing next song on que (if not empty).
    PiPod.scan_switches()
    pressed = PiPod.getKeyPressed()   # If no key was pressed, returns -1.
    if( pressed != -1 ):
        # This code only runs if a key was pressed.
        PiPod.clearKeyPressed()
        if pressed == K_ESCAPE:    # Button on the top upper left. Moves UP the menu tree.
            if menu.menuDict["current"] != "musicController":
                action = menu.escape()

        elif pressed == K_u:
            music.volumeUp()
            refreshNow = True

        elif pressed == K_d:
            music.volumeDown()
            refreshNow = True

        elif pressed == K_UP:      # "up" arrow on the front navigation button array.
            if menu.menuDict["current"] == "musicController":
                menu.gotomenu()
            else:
                action = menu.up()

        elif pressed == K_DOWN:
            if menu.menuDict["current"] != "musicController":
                action = menu.down()

        elif pressed == K_LEFT:
            # Before calling the code to handle the keypress, check the status of the K_DOWN button.
            state17 = PiPod.isPressed(17)     # state17 = 1 (DOWN button NOT pressed) or 0 (DOWN button IS pressed).
            if( menu.menuDict["current"] == "musicController" ):
                if( state17 == 1 ):
                    music.prev()
                else:
                    music.backup( 5000 )   # Back up 5 seconds
                    refreshNow = True
            else:
                # DOWN+LEFT and DOWN+RIGHT do small jumps up/down a list.
                action = menu.left( state17 )

        elif pressed == K_RIGHT:
            # Before calling the code to handle the keypress, check the status of the K_DOWN button.
            state17 = PiPod.isPressed(17)     # state17 = 1 (DOWN button NOT pressed) or 0 (DOWN button IS pressed).
            if( menu.menuDict["current"] == "musicController" ):
                if( state17 == 1 ):
                    music.next()
                else:
                    music.jumpForward( 5000 )   # Jump forward 5 seconds
                    refreshNow = True
            else:
                # DOWN+LEFT and DOWN+RIGHT do small jumps up/down a list.
                action = menu.right( state17 )

        elif pressed == K_RETURN:    # Center navigation button
            if menu.menuDict["current"] == "musicController":
                music.playPause()
            else:
                currentMode = music.getPlaybackMode()
                currentSongInformation = music.getSong()
                action = menu.select( currentMode, currentSongInformation )
                if action == "playGotoTop":
                    songSelectedItem = 0     # Play starting at the top of the list
                    music.loadList(menu.menuDict["Queue"], songSelectedItem )
                    menu.upTree(2)
                elif action == "play":
                    songSelectedItem = menu.getSelectedItem()    # Play the list starting at the highlighted item
                    music.loadList(menu.menuDict["Queue"], songSelectedItem )
                    menu.upTree(2)
                elif action == "switch2Genre":    # Keep playing current song. Wipe list of prior songs. Append Que.
                    music.wipePrior()
                    music.insertList( menu.menuDict["Queue"] )
                    menu.upTree(2)
                #elif action == "clearQueue":
                    #menu.menuDict["Queue"] = []
                    #music.clearQueue()
                elif action == "updateLibrary":
                    view.popUp("Updating Library")
                    music.player.stop
                    music.updateLibrary()  # Re-create the info.csv file
                    menu.loadMetadata()    # Re-read the info.csv file
                    menu.setUpdateFlag()
                elif action == "shutdown":
                    #view.popUp("Shutting down now\nThank You\nFor Playing.")
                    view.shutdownImage()
                    stopRefreshing = True
                    os.system("sudo shutdown now")
                elif action == "playAtIndex":
                    if menu.menuDict["selectedItem"] == 0:
                        music.clearQueue()
                        menu.menuDict["Queue"] = []
                    else:
                        music.playAtIndex(menu.menuDict["selectedItem"]-1)
                elif action == "setSongSelectedItem":
                    # Change menuDict["selectedItem"] so that the currently-playing Song is centered on the list.
                    songList = list( menu.menuDict["Songs"] )
                    thisSong = music.playlist[music.currentSongIndex]
                    if thisSong != ['', '', '', '', '', '']:
                        thisIndex = songList.index( thisSong )
                        menu.setSelectedItem( thisIndex )
                elif action == "setAlbumSelectedItem":
                    # Change menuDict["selectedItem"] so that the currently-playing song's Album is centered.
                    # Find the album of the current song.
                    thisSong = music.playlist[music.currentSongIndex]
                    if thisSong != ['', '', '', '', '', '']:
                        thisAlbum = thisSong[2]   # [2] points to the Album name for this song
                        # Now get the index of that album on the list of Albums.
                        albumList = list( menu.menuDict["Albums"] )
                        thisIndex = albumList.index( thisAlbum )
                        menu.setSelectedItem( thisIndex )
                elif action == "setArtistSelectedItem":
                    # Change menuDict["selectedItem"] so that the currently-playing song's Artist is centered.
                    # Find the artist of the current song.
                    thisSong = music.playlist[music.currentSongIndex]
                    if thisSong != ['', '', '', '', '', '']:
                        thisArtist = thisSong[1]   # [1] points to the Artist name of the song
                        # Now get the index of that artist on the list of Artists.
                        artistList = list( menu.menuDict["Artists"] )
                        thisIndex = artistList.index( thisArtist )
                        menu.setSelectedItem( thisIndex )
                elif action == "setGenreSelectedItem":
                    # Change menuDict["selectedItem"] so that the currently-playing song's Album is centered.
                    # Find the album of the current song.
                    thisSong = music.playlist[music.currentSongIndex]
                    if thisSong != ['', '', '', '', '', '']:
                        thisGenre = thisSong[4]     # [4] points to the Genre of the song
                        # Now get the index of that genre on the list of Genres.
                        genreList = list( menu.menuDict["Genres"] )
                        thisIndex = genreList.index( thisGenre )
                        menu.setSelectedItem( thisIndex )
                elif action == "EQOn":
                    music.enableEQ()
                elif action == "EQOff":
                    music.disableEQ()
                elif (action == "Normal" or action == "Shuffle" or action == "Repeat1"):
                    view.setPlayMode( action ) # Used to show the current play mode on the "set mode" screen
                    currentMode = music.getPlaybackMode()
                    if( currentMode != action ):
                        menu.setUpdateFlag()
                        music.setPlaybackMode(action)
                        # Now fill the playback que according to the new Playback Mode
                        if action == "Shuffle":
                            music.shuffle()
                        if action == "Normal":
                            music.unshuffle()
                elif action == "insertQueue":    # Take the list of currently-playing songs, and insert the Queue into it.
                    music.insertList( menu.menuDict["Queue"] )
                    menu.upTree(2)     # Set screen back at top-level screen
                elif action == "showTopScreen":
                    menu.upTree(2)
                #else:
                    #print("No command found for that keypress")
        # The next line gets executed every time a key was pressed.
        pass

    # Done handling key presses, so continue.
    updateScreenCounter += 1
    if( ((updateScreenCounter >= refreshTime) or (refreshNow)) and (stopRefreshing == False) ):
        # This code only runs once every 5 seconds, or if some code specifically requested it.
        refreshNow = False
        updateScreenCounter = 0
        if ( menu.menuDict["current"] == "musicController" ):
            status = PiPod.getStatus()         # Reads battery voltage
            if( float(status[1]) <= 3.15 ):
                # If battery voltage is too low, shutdown the unit.
                view.shutdownImage()
                stopRefreshing = True
                os.system("sudo shutdown now")
            songMetadata = music.getStatus()   # Get song length, how far in, song info, vol, playlist, index of current song
            temp = view.update(status, menu.menuDict, songMetadata) # Creates the screen and writes to frame buffer
            temp = view.partialUpdate(status, menu.menuDict, songMetadata) # Only upates the time into song, and the bar.
            view.partialRefresh()   # No screen flash
            #view.setBaseImage()    # Causes screen flash

    # Now we check to see if any Class has modified the screen.
    if( needToUpdate() and (stopRefreshing == False) ):
        status = PiPod.getStatus()         # Reads battery voltage
        songMetadata = music.getStatus()   # Get song length, how far in, song info, vol, playlist, index of current song
        temp = view.update(status, menu.menuDict, songMetadata) # Creates the screen and writes to frame buffer
        view.setBaseImage()

    time.sleep(0.1) # Pause 0.1 seconds. No need to check for key presses faster than that.

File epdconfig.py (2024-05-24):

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

import os
import logging
import sys
import time
import subprocess

logger = logging.getLogger(__name__)


class RaspberryPi:
    # Pin definition
    RST_PIN  = 16
    CS_PIN   = 4
    BUSY_PIN = 14
    PWR_PIN  = 23
    DC_PIN = 15

    def __init__(self):
        import spidev
        import gpiozero

        #print("Just entered __init__")
        self.SPI = spidev.SpiDev()
        self.GPIO_RST_PIN    = gpiozero.LED(self.RST_PIN)  #17
        self.GPIO_CS_PIN     = gpiozero.LED(self.CS_PIN) #8
        self.GPIO_PWR_PIN    = gpiozero.LED(self.PWR_PIN)  #18
        self.GPIO_BUSY_PIN   = gpiozero.Button(self.BUSY_PIN, pull_up = False) #24
        self.GPIO_DC_PIN     = gpiozero.LED(self.DC_PIN)  #25

    def digital_write(self, pin, value):
        if pin == self.RST_PIN:
            if value:
                self.GPIO_RST_PIN.on()
            else:
                self.GPIO_RST_PIN.off()
        elif pin == self.DC_PIN:
            if value:
                self.GPIO_DC_PIN.on()
            else:
                self.GPIO_DC_PIN.off()
        # elif pin == self.CS_PIN:
        #     if value:
        #         self.GPIO_CS_PIN.on()
        #     else:
        #         self.GPIO_CS_PIN.off()
        elif pin == self.PWR_PIN:
            if value:
                self.GPIO_PWR_PIN.on()
            else:
                self.GPIO_PWR_PIN.off()

    def digital_read(self, pin):
        if pin == self.BUSY_PIN:
            return self.GPIO_BUSY_PIN.value
        elif pin == self.RST_PIN:
            return self.RST_PIN.value
        elif pin == self.DC_PIN:
            return self.DC_PIN.value
        # elif pin == self.CS_PIN:
        #     return self.CS_PIN.value
        elif pin == self.PWR_PIN:
            return self.PWR_PIN.value

    def delay_ms(self, delaytime):
        time.sleep(delaytime / 1000.0)

    def spi_writebyte(self, data):
        self.SPI.writebytes(data)

    def spi_writebyte2(self, data):
        self.SPI.writebytes2(data)

    def module_init(self):
        self.GPIO_PWR_PIN.on()

        #SPI device, bus = 0, device = 0
        #self.SPI.open(0, 0)
        # In Rasp Pi 5, use (0,0). In Rasp Zero W 2, use (0,1)
        self.SPI.open(0, 1)
        self.SPI.max_speed_hz = 4000000
        self.SPI.mode = 0b00
        return 0

    def module_exit(self, cleanup=False):
        logger.debug("spi end")
        self.SPI.close()

        
        self.GPIO_RST_PIN.off()
        self.GPIO_DC_PIN.off()
        self.GPIO_PWR_PIN.off()
        logger.debug("close 5V, Module enters 0 power consumption ...")
        
        if cleanup:
            self.GPIO_RST_PIN.close()
            self.GPIO_DC_PIN.close()
            # self.GPIO_CS_PIN.close()
            self.GPIO_PWR_PIN.close()
            self.GPIO_BUSY_PIN.close()

        



class JetsonNano:
    # Pin definition
    RST_PIN  = 17
    DC_PIN   = 25
    CS_PIN   = 8
    BUSY_PIN = 24
    PWR_PIN  = 18

    def __init__(self):
        import ctypes
        find_dirs = [
            os.path.dirname(os.path.realpath(__file__)),
            '/usr/local/lib',
            '/usr/lib',
        ]
        self.SPI = None
        for find_dir in find_dirs:
            so_filename = os.path.join(find_dir, 'sysfs_software_spi.so')
            if os.path.exists(so_filename):
                self.SPI = ctypes.cdll.LoadLibrary(so_filename)
                break
        if self.SPI is None:
            raise RuntimeError('Cannot find sysfs_software_spi.so')

        import Jetson.GPIO
        self.GPIO = Jetson.GPIO

    def digital_write(self, pin, value):
        self.GPIO.output(pin, value)

    def digital_read(self, pin):
        return self.GPIO.input(self.BUSY_PIN)

    def delay_ms(self, delaytime):
        time.sleep(delaytime / 1000.0)

    def spi_writebyte(self, data):
        self.SPI.SYSFS_software_spi_transfer(data[0])

    def spi_writebyte2(self, data):
        for i in range(len(data)):
            self.SPI.SYSFS_software_spi_transfer(data[i])

    def module_init(self):
        self.GPIO.setmode(self.GPIO.BCM)
        self.GPIO.setwarnings(False)
        self.GPIO.setup(self.RST_PIN, self.GPIO.OUT)
        self.GPIO.setup(self.DC_PIN, self.GPIO.OUT)
        self.GPIO.setup(self.CS_PIN, self.GPIO.OUT)
        self.GPIO.setup(self.PWR_PIN, self.GPIO.OUT)
        self.GPIO.setup(self.BUSY_PIN, self.GPIO.IN)
        
        self.GPIO.output(self.PWR_PIN, 1)
        
        self.SPI.SYSFS_software_spi_begin()
        return 0

    def module_exit(self):
        logger.debug("spi end")
        self.SPI.SYSFS_software_spi_end()

        logger.debug("close 5V, Module enters 0 power consumption ...")
        self.GPIO.output(self.RST_PIN, 0)
        self.GPIO.output(self.DC_PIN, 0)
        self.GPIO.output(self.PWR_PIN, 0)

        self.GPIO.cleanup([self.RST_PIN, self.DC_PIN, self.CS_PIN, self.BUSY_PIN, self.PWR_PIN])
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

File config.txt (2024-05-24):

# For more options and information see
# http://rptl.io/configtxt
# Some settings may impact device functionality. See link above for details

# Uncomment some or all of these to enable the optional hardware interfaces
dtparam=i2c_arm=on
#dtparam=i2s=on
dtparam=spi=on
dtoverlay=disable-wifi
dtoverlay=disable-bt

# Enable audio (loads snd_bcm2835)
#dtparam=audio=on

# Additional overlays and parameters are documented
# /boot/firmware/overlays/README

# Automatically load overlays for detected cameras
#camera_auto_detect=1

# Automatically load overlays for detected DSI displays
#display_auto_detect=1

# Automatically load initramfs files, if found
auto_initramfs=1

# Enable DRM VC4 V3D driver
#dtoverlay=vc4-kms-v3d
#max_framebuffers=2

# Don't have the firmware create an initial video= setting in cmdline.txt.
# Use the kernel's default instead.
disable_fw_kms_setup=1

# Run in 64-bit mode
arm_64bit=1

# Disable compensation for displays with overscan
disable_overscan=1

# Run as fast as firmware / board allows
#arm_boost=1
arm_freq=150
core_freq=150
over_voltage=-4

[cm4]
# Enable host mode on the 2711 built-in XHCI USB controller.
# This line should be removed if the legacy DWC2 controller is required
# (e.g. for USB device mode) or if USB support is not required.
otg_mode=1

[all]

dtoverlay=hifiberry-dac

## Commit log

2024-04-12 Add config.txt
    [config.txt]
2024-05-14 Added BOM
    [BOM_epaper.xlsx]
2024-05-14 Added schematic
2024-05-15 Removed old pin assignment comment lines
2024-05-15 Removed sleep & reboot
    [device.py, main.py, navigation.py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]
2024-05-22 Added component costs
    [BOM_epaper.xlsx]
2024-05-22 Added more cost info
    [BOM_epaper.xlsx]
2024-05-29 Initial check-in
    [PiPod_Frame_v4 v6.stl, PiPod_TopCase v18.stl, PiPod_case_bottom v8.stl]
2024-05-31 Adding gerbers (v2)
2024-05-31 Version 2
    [Button (side).stl, PiPod_Navigation_buttons_v3 v2.stl, PiPod_TopCase v21.stl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]
2024-05-31 Add Rev2 schematic
2024-06-04 Increased some wall thicknesses for DFM
    [PiPod_Frame_v4 v8.stl, PiPod_TopCase v23.stl]
2024-06-05 2nd source for Q2,Q5 FET
2024-06-06 Removed debug print()
2024-06-07 Fixed 'nav buttons' bug
    [display.py, main.py, navigation.py]
2024-06-09 "Play by ..." now puts all matching songs on que
2024-06-10 Minor cleanups and bug fixes
    [navigation.py]
2024-06-10 Fixed list boundary under-run bug
    [navigation.py]
2024-06-10 Propagated prev fix to Albums/Genres,etc...
    [navigation.py]
2024-06-15 v3 gerbers: minor fix to the e-paper recepticle
2024-06-15 Adding Rev3 case files
    [PiPod_Frame_v4 v10.stl, PiPod_Navigation_buttons_v3 v3.stl, PiPod_TopCase v30.stl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]
2024-06-17 Added album/genre/track to top screen
2024-06-18 Now plays an album in track order
2024-06-19 Added "Switch to this Genre" feature
2024-06-20 Added skip forward/back 5 sec feature
    [main.py, playback.py]
2024-06-28 Displays proper voltage on power-up, also centers '/'
2024-07-04 DFM fix: updated e-paper screen socket footprint
